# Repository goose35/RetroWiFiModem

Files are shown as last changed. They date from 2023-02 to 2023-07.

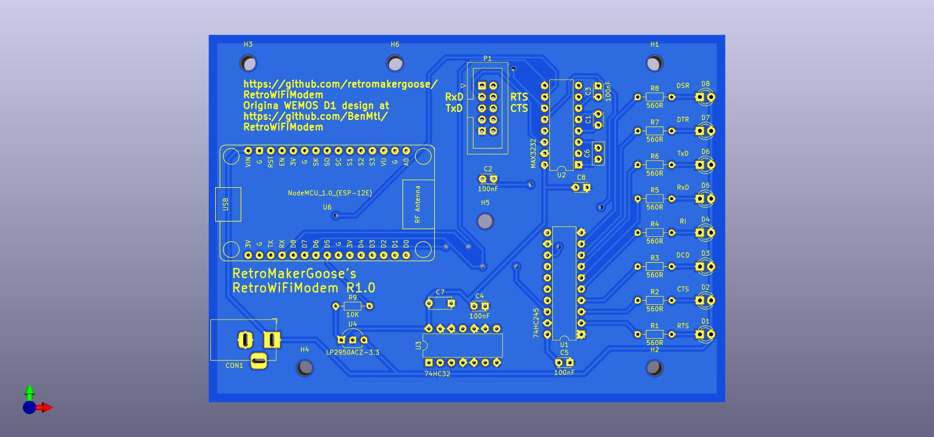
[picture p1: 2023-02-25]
images/MyRetroWiFiModemF.jpg

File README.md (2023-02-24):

# Retro WiFi modem

Forked from BenMtl's repository.
Modified to use a NodeMCU board, of which i had several in waiting.
Will be using on a C64, BBC Micro and Amiga A1200 so will require several adapter leads

# Important Note

Please note that there are 2 standards (pin-outs) for the 10 pin motherboard connector
AT/Everex or Intel/DTK
This modem is using the Intel/DTK pinout
Therefore be aware of this when buying/making your connections to the modem serial port

## The Software

In a nod to its popularity, the command set I used largely follows that
used in [Paul Rickards' WiFi232](http://biosrhythm.com/?page_id=1453)
modem. Even if the innards are completely different, it made sense to
make it *work* like what people were already used to. There's a reason
everyone's been copying the Hayes command set for almost 40 years!

### First time setup

The default serial configuration is 1200bps, 8 data bits, no parity, 1
stop bit.

Here's the commands you need to set up the modem to automatically
connect to your WiFi network:

1. `AT$SSID=your WiFi network name` to set the WiFi network that the
modem will connect to when it powers up.
2. `AT$PASS=your WiFi network password` to set the password for the
network.
3. `ATC1` to connect to the network.
4. Optional stuff:
   * `AT$SB=speed` to set the default serial speed.
   * `AT$SU=dps` to set the data bits, parity and stop bits.
   * `ATNETn` to select whether or not to use Telnet protocol.
   * `AT&Kn` to use RTS/CTS flow control or not.
5. `AT&W` to save the settings.

Once you've done that, the modem will automatically connect to your WiFi
network on power up and will be ready to "dial up" a connection with
ATDT.

### Command Reference

Multiple AT commands can be typed in on a single line. Spaces between
commands are allowed, but not within commands (i.e. AT S0=1 X1 Q0 is
fine; ATS 0=  1 is not). Commands that take a string as an argument
(e.g. AT$SSID=, AT$TTY=) assume that *everything* that follows is a part
of the string, so no commands are allowed after them.

Command | Details
------- | -------
+++     | Online escape code. Once your modem is connected to another device, the only command it recognises is an escape code of a one second pause followed by three typed plus signs and another one second pause, which puts the modem back into local command mode.
A/      | Repeats the last command entered. Do not type AT or press Enter.
AT      | The attention prefix that precedes all command except A/ and +++.
AT?     | Displays a help cheatsheet.
ATA     | Force the modem to answer an incoming connection when the conditions for auto answer have not been satisfied.
ATC?<br>ATC*n* | Query or change the current WiFi connection status. A result of 0 means that the modem is not connected to WiFi, 1 means the modem is connected. The command ATC0 disconnects the modem from a WiFi connection. ATC1 connects the modem to the WiFi.
ATDS*n* | Calls the host specified in speed dial slot *n* (0-9).
ATDT<i>[+=-]host[:port]</i> | Tries to establish a WiFi TCP connection to the specified host name or IP address. If no port number is given, 23 (Telnet) is assumed. You can also use ATDT to dial one of the speed dial slots in one of two ways:<br><br><ul><li>The alias in each speed dial slot is checked to see if it matches the specified hostname.</li><li>A host specified as 7 identical digits dials the slot indicated by the digit. (i.e. 2222222 would speed dial the host in slot 2).</li></ul>Preceding the host name or IP address with a +, = or - character overrides the ATNET setting for the period of the connection.<br><br><ul><li>**+** forces NET2 (fake Telnet)</li><li>**=** forces NET1 (real Telnet)</li><li>**-** forces NET0 (no Telnet)</li></ul>Once the dial attempt has begun, pressing any key before the connection is established will abort the attempt.
ATE?<br>ATE*n* | Command mode echo. Enables or disables the display of your typed commands.<br><br><ul><li>E0 Command mode echo OFF. Your typing will not appear on the screen.</li><li>E1 Command mode echo ON. Your typing will appear on the screen.</li></ul>
ATGET*http&#58;//host[/page]* | Displays the contents of a website page. **https** connections are not supported. Once the contents have been displayed, the connection will automatically terminate.
ATH | Hangs up (ends) the current connection.
ATI | Displays the current network status, including sketch build date, WiFi and call connection state, SSID name, IP address, and bytes transferred.
ATNET?<br>ATNET*n* | Query or change whether telnet protocol is enabled. A result of 0 means that telnet protocol is disabled; 1 is *Real* telnet protocol and 2 is *Fake* telnet protocol. If you are connecting to a telnet server, it may expect the modem to respond to various telnet commands, such as terminal name (set with `AT$TTY`), terminal window size (set with `AT$TTS`) or terminal speed. Telnet protocol should be enabled for these sites, or you will at best see occasional garbage characters on your screen, or at worst the connection may fail.<br><br>The difference between *real* and *fake* telnet protocol is this: with *real* telnet protocol, a carriage return (CR) character being sent from the modem to the telnet server always has a NUL character added after it. The implementation of the telnet protocol used by some BBSes doesn't properly strip out the NUL character. When connecting to such BBSes (Particles! is one), use *fake* telnet.<br><br>When using *real* telnet protocol, when the telnet server sends a CR character followed by a NUL character, only the CR character will be sent to the serial port; the NUL character will be silently stripped out. With *fake* telnet protocol, the NUL will be passed through.
ATO | Return online. Use with the escape code (+++) to toggle between command and online modes.
ATQ?<br>ATQ*n* | Enable or disable the display of result codes. The default is Q0.<br><br><ul><li>Q0 Display result codes.</li><li>Q1 Suppress result codes (quiet).</li></ul>
ATRD<br>ATRT | Displays the current UTC date and time from NIST in the format *YY-MM-DD HH:MM:SS*. A WiFi connection is required and you cannot be connected to another site.
ATS0?<br>ATS0=*n* | Display or set the number of "rings" before answering an incoming connection. Setting `S0=0` means "don't answer".
ATV?<br>ATV*n* | Display result codes in words or numbers. The default is V1.<br><br><ul><li>V0 Display result codes in numeric form.</li><li>V1 Display result codes in text form.</li></ul>
ATX?<br>ATX*n* | Control the amount of information displayed in the result codes. The default is X1 (extended codes).<br><br><ul><li>X0 Display basic codes (CONNECT, NO CARRIER)</li><li>X1 Display extended codes (CONNECT speed, NO CARRIER (connect time))</li></ul>
ATZ | Resets the modem.
AT&F | Reset the NVRAM contents and current settings to the sketch defaults. All settings, including SSID name, password and speed dial slots are affected.
AT&K?<br>AT&K*n* | Data flow control. Prevents the modem's buffers for received and transmitted from overflowing.<br><br><ul><li>&K0 Disable data flow control.</li><li>&K1 Use hardware flow control. Requires that your computer and software support Clear to Send (CTS) and Request to Send (RTS) at the RS-232 interface.</li></ul>
AT&R?<br>AT&R=*server pwd* | Query or change the password for incoming connections. If set, the user has 3 chances in 60 seconds to enter the correct password or the modem will end the connection.
AT&V*n* | Display current or stored settings.<br><br><ul><li>&V0 Display current settings.</li><li>&V1 Display stored settings.</li></ul>
AT&W | Save current settings to NVRAM.
AT&Zn?<br>AT&Z*n*=*host[:port],alias* | Store up to 10 numbers in NVRAM, where *n* is the position 0-9 in NVRAM, and *host[:port]* is the host string, and *alias* is the speed dial alias name. The host string may be up to 50 characters long, and the alias string may be up to 16 characters long.<br><br>Example: `AT&Z2=particlesbbs.dyndns.org:6400,particles`<br><br>This number can then be dialed in any of the following ways:<br><br><ul><li>`ATDS2`</li><li>`ATDTparticles`</li><li>`ATDT2222222`</li></ul>
AT$AE?<br>AT$AE=*startup AT cmd* | Query or change the command line to be executed when the modem starts up.
AT$BM?<br>AT$BM=*server busy msg* | Query or change a message to be returned to an incoming connection if the modem is busy (i.e. already has a connection established).
AT$MDNS<br>AT$MDNS=*mDNS name* | Query or change the mDNS network name (defaults to "espmodem"). When a non zero TCP port is defined, you can telnet to that port with **telnet mdnsname.local port**.
AT$PASS?<br>AT$PASS=*WiFi pwd* | Query or change the current WiFi password. The password is case sensitive. Clear the password by issuing the set command with no password. The maximum length of the password is 64 characters.
AT$SB?<br>AT$SB=*n* | Query or change the current baud rate. Valid values for "n" are 110, 300, 450, 600, 710, 1200, 2400, 4800, 9600, 19200, 38400, 57600, 76800 and 115200. Any other value will return an ERROR message. The default baud rate is 1200. The Retro WiFi modem does not automatically detect baud rate like a dial-up modem. The baud rate setting must match that of your terminal to operate properly. It will display garbage in your terminal otherwise.
AT$SP?<br>AT$SP=*n* | TCP server port to listen on. A value of 0 means that the TCP server is disabled, and no incoming connections are allowed.
AT$SSID?<br>AT$SSID=*ssid name* | Query or change the current SSID to the specified name. The given SSID name is case sensitive. Clear the SSID by issuing the set command with no SSID. The maximum length of the SSID name is 32 characters.
AT$SU?<br>AT$SU=*dps* | Query or change the current number of data bits ('d'), parity ('p') and stop bits ('s") of the serial UART. Valid values for 'd' are 5, 6, 7 or 8 bits. Valid values for 'p' are (N)one, (O)dd or (E)ven parity. Valid values for 's' are 1 or 2 bits. The default settings are 8N1. The UART setting must match your terminal to work properly.
AT$TTL?<br>AT$TTL=*telnet location* | Query or change the Telnet location value to be returned when the Telnet server issues a SEND-LOCATION request. The default value is "Computer Room".
AT$TTS?<br>AT$TTS=*WxH* | Query or change the window size (columns x rows) to be returned when the Telnet server issues a NAWS (Negotiate About Window Size) request. The default value is 80x24. For terminals that are smaller than 80x24, setting these values appropriately will enable paging on the help (AT?) and network status (ATI) commands.
AT$TTY?<br>AT$TTY=*terminal type* | Query or change the terminal type to be returned when the Telnet server issues a TERMINAL-TYPE request. The default value is "ansi".
AT$W?<br>AT$W=*n* | Startup wait.<br><br><ul><li>$W=0 Startup with no wait.</li><li>$W=1 Wait for the return key to be pressed at startup.</li></ul>

### Updating the Software

While I liked the idea of being able to update the software OTA, it
seemed to make more sense in my situation to be able to *push* a new
version as I built it rather than have the modem *pull* it. So that's
what I did. It uses the default OTA upload capability built into the
Arduino IDE.

**Jan 24/22:** It's been reported that the ESP8266 core is slightly
snafu'd at the moment, and that it's breaking things in the modem
software. As a workaround, I've added the bin file that gets uploaded
to the modem in the repository. I haven't updated my ESP8266 core in
ages; "if it isn't broken, don't break it", and everything still works
for me. The bin file can be uploaded with the *espota.py* tool in the
ESP8266 tool directory tree.

(If TPTB have deleted/renamed/moved that tool in the current core,
you'll have to figure out how to do a manual OTA update.)

### RTS/CTS handshaking and a dead spin loop issue

Something I noticed with ESP8266 software that puzzled me was the
number of places I saw a series of Serial print statements being broken
up with calls to yield(), like so:

```
   Serial.print("Hello world!\n");
   yield();
   Serial.print("How are you today?\n");
   yield();
```
It didn't take long to figure out what was going on; The print() call
was blocking, and at lower baud rates, even printing a few relatively
short strings was enough to cause the watchdog to bark and cause a
reset. So the repetitive yield() calls were an attempt to feed the
watchdog often enough to keep it from barking.

What does this have to do with RTS/CTS handshaking? Simply put,
lowering RTS for more than a few seconds was causing the watchdog to
bark as well. So I started digging.

In cores/esp8266/uart.cpp I found the following function:

```
static void
uart_do_write_char(const int uart_nr, char c)
{
    while(uart_tx_fifo_full(uart_nr));

    USF(uart_nr) = c;
}
```

This is the low level function that everything calls to send a character
out the serial port. The cause of the watchdog barking is in the dead
spin while loop. It waits until there's room in the transmit FIFO to add
another character. So if RTS/CTS handshaking is enabled, and RTS is low
for longer than the watchdog likes: woof.

What I did to quiet the watchdog down both when sending long strings at
low baud rates and during long waits for RTS to come active again was to
add a yield() call to the dead spin while loop, like so:

```
static void
uart_do_write_char(const int uart_nr, char c)
{
    while(uart_tx_fifo_full(uart_nr))
      yield();

    USF(uart_nr) = c;
}
```

This way, no matter how long the code has to wait for space in the
transmit FIFO, the watchdog is kept well fed and quiet.

## Status

Is a personal project like this ever *really* finished? I've had two
units assembled and in use since the spring of 2020, and while there's
been some software changes since then, I really don't expect any more.
There are no outstanding bugs that I'm aware of, and no new features on
my wish list. For the time being at least, I think it's complete.

### Linux, Telnet, Zmodem and downloading binary files

Have you used the modem to 'dial' into a Linux box? And have you done a
`sz binary_file` on the Linux box? And at a completely reproducible
point in the file, has the connection dropped? But other binary files
work just fine? Then read on.

This drove me slightly batty for months. I finally narrowed it down to
trying to send blocks of binary data with a large number of FF bytes. I
eventually created a test file consisting of 2K of FF and used that to
test with. I could download it through the modem with Xmodem just fine.
Ymodem also worked if I kept the block size down to 128 bytes - but the
connection would drop instantly if I tried sending 1K blocks. Same thing
with Zmodem.

In fact, if I just tried `cat binary_file`, the connection would
drop. Which eventually got me thinking. Sitting at the console on my
main Linux box, I telnet'd to the same box and logged in. No WiFi modem
involved anywhere, just a telnet session on the console to the same box.
I then did a `cat binary_file`. The telnet connection dropped, and I
was back in my original session.

It's the Linux telnet daemon. Not the modem at all.

To prove it to myself, I hooked up WiFi modems to two systems on their
serial ports and had one dial into the other. I could send the all FF
binary file back and forth with Zmodem and Ymodem, no trouble at all.

But you really, really need to download that binary file through the
modem from a telnet connection to a Linux box? You're not going to be
able to use Zmodem. Ymodem will work (the sy command defaults to 128
byte blocks), as will Xmodem. But not Zmodem.

Oddly enough, the telnet daemon has no trouble *receiving* the all FF
binary file. Only sending it. Your guess as to why is probably better
than mine.

## References

* [WiFi232 - An Internet Hayes Modem for your Retro Computer](http://biosrhythm.com/?page_id=1453)<br>
* [WiFi232's Evil Clone](https://forum.vcfed.org/index.php?threads/wifi232s-evil-clone.1070412/)<br>
* [Jussi Salin's Virtual modem for ESP8266](https://github.com/jsalin/esp8266_modem)<br>
* [Stardot's ESP8266 based virtual modem](https://github.com/stardot/esp8266_modem)<br>
* [Roland Juno's ESP8266 based virtual modem](https://github.com/RolandJuno/esp8266_modem)

## Acknowledgements

* A whole lot of people owe a big vote of thanks to Jussi Salin for
releasing their virtual modem code for the ESP8266 and starting the
ball rolling.
* Paul Rickards for an amazing bit of hardware to draw inspiration from.
* All the Stardot contributors for their work.
* And, of course, Dennis C. Hayes for creating something so simple and
elegant that has stood the test of time.

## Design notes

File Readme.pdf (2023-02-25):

Doc Rev. 1.0.0

Page 1 of 9

### 24 February 2023

Stephen Orton

# Retro WiFi modem

Introduction
This is my version of the RetroWiFiModem. All I have done is modify the PCB layout to use a Node MCU development board instead of the original Wemos D1 Mini

The code was also modified to include Node MCU support

Important Note
Please note that there are 2 standards (pin-outs) for the 10 pin motherboard connector AT/Everex or Intel/DTK
This modem is using the Intel/DTK pinout
Therefore be aware of this when buying/making your connections to the modem serial port

Post Build Setup
The default serial configuration is 1200bps, 8 data bits, no parity, 1
stop bit.
1. `AT$SSID=your WiFi network name` to set the WiFi network that the modem will connect to when it powers up.
2. `AT$PASS=your WiFi network password` to set the password for the network.
3. `ATC1` to connect to the network.

### 4. Optional stuff:

* `AT$SB=speed` to set the default serial speed.
* `AT$SU=dps` to set the data bits, parity and stop bits.
* `ATNETn` to select whether or not to use Telnet protocol.
* `AT&Kn` to use RTS/CTS flow control or not.
5. `AT&W` to save the settings.

Once you've done that, the modem will automatically connect to your WiFi network on power up and will be ready to "dial up" a connection with ATDT. Command Reference
Multiple AT commands can be typed in on a single line. Spaces between commands are allowed, but not within commands (i.e. AT S0=1 X1 Q0 is fine; ATS 0= 1 is not). Commands that take a string as an argument
(e.g. AT$SSID=, AT$TTY=) assume that *everything* that follows is a part of the string, so no commands are allowed after them.

Page 2 of 9

Command | Details
+++ | Online escape code. Once your modem is connected to another device, the only command it recognises is an escape code of a one second pause followed by three typed plus signs and another one second pause, which puts the modem back into local command mode.
A/ | Repeats the last command entered. Do not type AT or press Enter.
AT | The attention prefix that precedes all command except A/ and +++.
AT? | Displays a help cheatsheet.
ATA | Force the modem to answer an incoming connection when the conditions for auto answer have not been satisfied.
ATC? ATC*n* | Query or change the current WiFi connection status. A result of 0 means that the modem is not connected to WiFi, 1 means the modem is connected. The command ATC0 disconnects the modem from a WiFi connection. ATC1 connects the modem to the WiFi.
ATDS*n* | Calls the host specified in speed dial slot *n* (0-9).
ATDT<i>[+=-
]host[:port]

Tries to establish a WiFi TCP connection to the specified host name or IP address. If no port number is given, 23 (Telnet) is assumed. You can also use ATDT to dial one of the speed dial slots in one of two ways:<br><br><ul><li>The alias in each speed dial slot is checked to see if it matches the specified hostname.</li><li>A host specified as 7 identical digits dials the slot indicated by the digit. (i.e. 2222222 would speed dial the host in slot 2).</li></ul>Preceding the host name or IP address with a +, = or - character overrides the ATNET setting for the period of the
connection.<br><br><ul><li>**+** forces NET2 (fake Telnet)</li><li>**=** forces NET1 (real Telnet)</li><li>**-** forces NET0 (no Telnet)</li></ul>Once the dial attempt has begun, pressing any key before the connection is established will abort the attempt.
ATE?
ATE*n*

Command mode echo. Enables or disables the display of your typed commands.<br><br><ul><li>E0 Command mode echo OFF. Your typing will not appear on the screen.</li><li>E1 Command mode echo ON. Your typing will appear on the screen.</li></ul>

Page 3 of 9

ATGET*http&#5 8;//host[/page] * | Displays the contents of a website page. **https** connections are not supported. Once the contents have been displayed, the connection will automatically terminate.
ATH | Hangs up (ends) the current connection.
ATI | Displays the current network status, including sketch build date, WiFi and call connection state, SSID name, IP address, and bytes transferred.

ATNET?
ATNET*n*

Query or change whether telnet protocol is enabled. A result of 0 means that telnet protocol is disabled; 1 is *Real* telnet protocol and 2 is *Fake* telnet protocol. If you are connecting to a telnet server, it may expect the modem to respond to various telnet commands, such as terminal name (set with `AT$TTY`), terminal window size (set with `AT$TTS`) or terminal speed. Telnet protocol should be enabled for these sites, or you will at best see occasional garbage characters on your screen, or at worst the connection may fail.<br><br>The difference between *real* and *fake* telnet protocol is this: with *real* telnet protocol, a carriage return (CR) character being sent from the modem to the telnet server always has a NUL character added after it. The implementation of the telnet protocol used by some BBSes doesn't properly strip out the NUL character. When connecting to such BBSes (Particles! is one), use *fake* telnet.<br><br>When using *real* telnet protocol, when the telnet server sends a CR character followed by a NUL character, only the CR character will be sent to the serial port; the NUL character will be silently stripped out. With *fake* telnet protocol, the NUL will be passed through.
ATO | Return online. Use with the escape code (+++) to toggle between command and online modes.
ATQ? ATQ*n* | Enable or disable the display of result codes. The default is Q0. Q0 Display result codes Q1 Suppress result codes (quiet).
ATRD ATRT | Displays the current UTC date and time from NIST in the format *YY-MM-DD HH:MM:SS*. A WiFi connection is required and you cannot be connected to another site.
ATS0? ATS0=*n* | Display or set the number of "rings" before answering an incoming connection. Setting `S0=0` means "don't answer".
ATV? | Display result codes in words or numbers. The default is V1.

Page 4 of 9

ATV*n* | V0 Display result codes in numeric form. V1 Display result codes in text form.</li></ul>
ATX? ATX*n* | Control the amount of information displayed in the result codes. The default is X1 (extended codes). Display basic codes (CONNECT, NO CARRIER). X1 Display extended codes (CONNECT speed, NO CARRIER (connect time))</li></ul>
ATZ | Resets the modem.
AT&F | Reset the NVRAM contents and current settings to the sketch defaults. All settings, including SSID name, password and speed dial slots are affected.
AT&K? AT&K*n* | Data flow control. Prevents the modem's buffers for received and transmitted from overflowing. &K0 Disable data flow control. &K1 Use hardware flow control. Requires that your computer and software support Clear to Send (CTS) and Request to Send (RTS) at the RS-232 interface.
AT&R? AT&R=*server pwd* | Query or change the password for incoming connections. If set, the user has 3 chances in 60 seconds to enter the correct password or the modem will end the connection.
AT&V*n* | Display current or stored settings. &V0 Display current settings. &V1 Display stored settings.
AT&W | Save current settings to NVRAM.
AT&Zn? AT&Z*n*=*host [:port],alias* | Store up to 10 numbers in NVRAM, where *n* is the position 0-9 in NVRAM, and *host[:port]* is the host string, and *alias* is the speed dial alias name. The host string may be up to 50 characters long, and the alias string may be up to 16 characters long. Example: `AT&Z2=particlesbbs.dyndns.org:6400,particles` This number can then be dialed in any of the following ways: `ATDS2` `ATDTparticles` `ATDT2222222`
AT$AE? AT$AE=*startup AT cmd* | Query or change the command line to be executed when the modem starts up.
AT$BM? AT$BM=*server busy msg* | Query or change a message to be returned to an incoming connection if the modem is busy (i.e. already has a connection established).
AT$MDNS AT$MDNS=*mD NS name* | Query or change the mDNS network name (defaults to "espmodem"). When a non zero TCP port is defined, you can telnet to that port with **telnet mdnsname.local port**.

Page 5 of 9

AT$PASS? AT$PASS=*WiFi pwd* | Query or change the current WiFi password. The password is case sensitive. Clear the password by issuing the set command with no password. The maximum length of the password is 64 characters.
AT$SB? AT$SB=*n* | Query or change the current baud rate. Valid values for "n" are 110, 300, 450, 600, 710, 1200, 2400, 4800, 9600, 19200, 38400, 57600, 76800 and 115200. Any other value will return an ERROR message. The default baud rate is 1200. The Retro WiFi modem does not automatically detect baud rate like a dial-up modem. The baud rate setting must match that of your terminal to operate properly. It will display garbage in your terminal otherwise.
AT$SP? AT$SP=*n* | TCP server port to listen on. A value of 0 means that the TCP server is disabled, and no incoming connections are allowed.
AT$SSID? AT$SSID=*ssid name* | Query or change the current SSID to the specified name. The given SSID name is case sensitive. Clear the SSID by issuing the set command with no SSID. The maximum length of the SSID name is 32 characters.
AT$SU? AT$SU=*dps* | Query or change the current number of data bits ('d'), parity ('p') and stop bits ('s") of the serial UART. Valid values for 'd' are 5, 6, 7 or 8 bits. Valid values for 'p' are (N)one, (O)dd or (E)ven parity. Valid values for 's' are 1 or 2 bits. The default settings are 8N1. The UART setting must match your terminal to work properly.
AT$TTL? AT$TTL=*telnet location* | Query or change the Telnet location value to be returned when the Telnet server issues a SEND-LOCATION request. The default value is "Computer Room".
AT$TTS? AT$TTS=*WxH* | Query or change the window size (columns x rows) to be returned when the Telnet server issues a NAWS (Negotiate About Window Size) request. The default value is 80x24. For terminals that are smaller than 80x24, setting these values appropriately will enable paging on the help (AT?) and network status (ATI) commands.
AT$TTY? AT$TTY=*termi nal type* | Query or change the terminal type to be returned when the Telnet server issues a TERMINAL-TYPE request. The default value is "ansi".
AT$W? AT$W=*n* | Startup wait $W=0 Startup with no wait. $W=1 Wait for the return key to be pressed at startup.

Page 6 of 9

Updating the Software
The software may be loaded in the normal way or you may use the default OTA upload capability built into the Arduino IDE to upload OTA

References
* WiFi232 - An Internet Hayes Modem for your Retro computer http://biosrhythm.com/?page_id=1453
- WiFi232's Evil Clone
(https://forum.vcfed.org/index.php?threads/wifi232s-evil-clone.1070412/)
- Jussi Salin's Virtual modem for ESP8266 (https://github.com/jsalin/esp8266_modem)
- Stardot's ESP8266 based virtual modem (https://github.com/stardot/esp8266_modem)
- Roland Juno's ESP8266 based virtual modem (https://github.com/RolandJuno/esp8266_modem)

Acknowledgements
- A whole lot of people owe a big vote of thanks to Jussi Salin for releasing their virtual modem code for the ESP8266 and starting the ball rolling.
- Paul Rickards for an amazing bit of hardware to draw inspiration from.
- All the Stardot contributors for their work.
- And, of course, Dennis C. Hayes for creating something so simple and elegant that has stood the test of time.

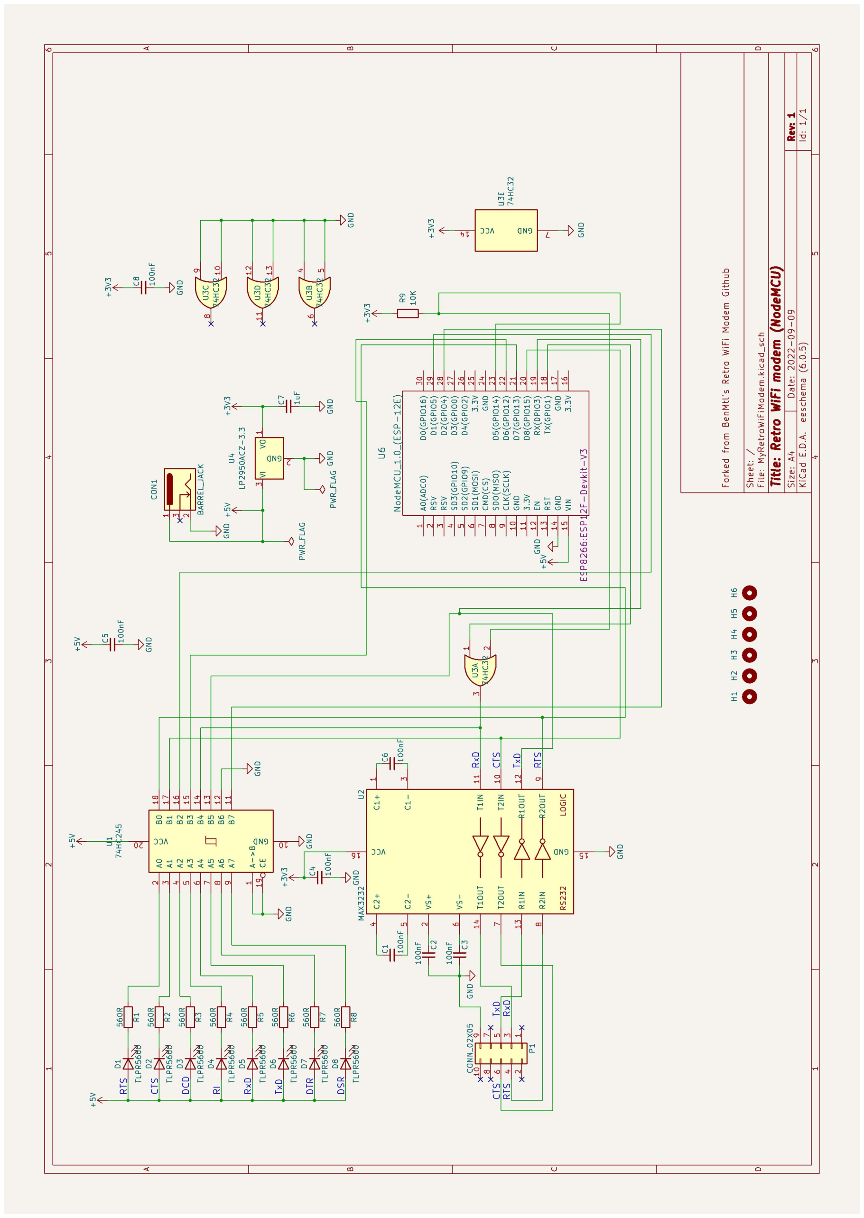
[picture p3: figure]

Page 7 of 9

Schematic

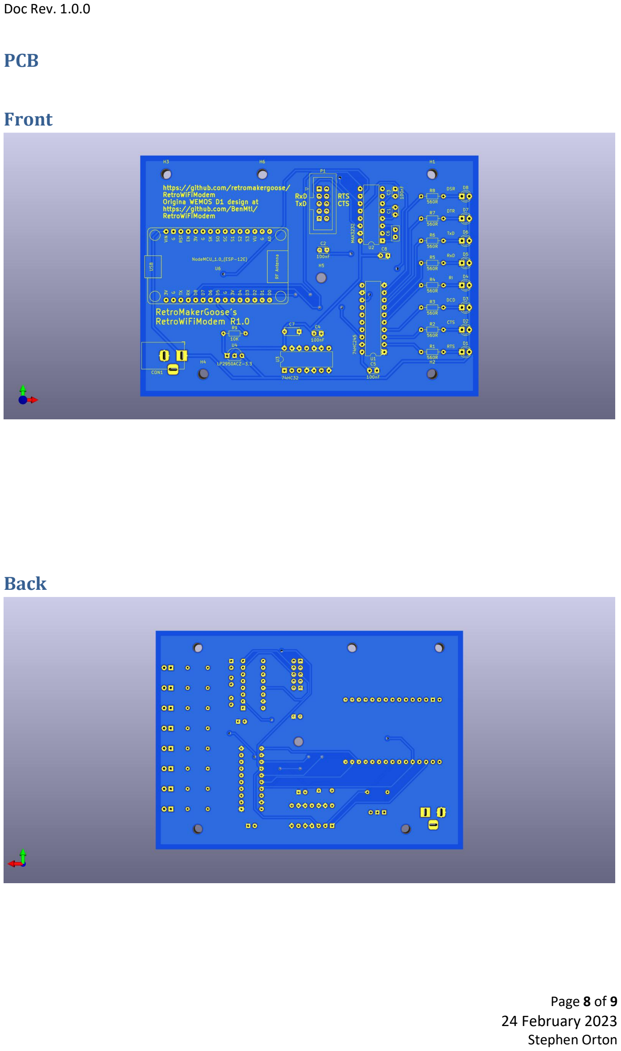
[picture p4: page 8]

Page 8 of 9

PCB

Front

Back

Page 9 of 9

BOM

C7, | 1 | 1uF | Unpolarized capacitor, small symbol
CON1, | 1 | BARREL_JACK | DC Barrel Jack with an internal switch
D1, D2, D3, D4, D5, D6, D7, D8, | 8 | TLPR5600 | Light emitting diode
H1, H2, H3, H4, H5, H6, | 6 | MountingHole | Mounting Hole without connection
P1, | 1 | CONN_02X05 | Generic connector, double row, 02x05, odd/even pin numbering scheme (row 1 odd numbers, row 2 even numbers), script generated (kicad-library-utils/schlib/autogen/connector/)
R1, R2, R3, R4, R5, R6, R7, R8, | 8 | 560R | Resistor
R9, | 1 | 10K | Resistor
U1, | 1 | 74HC245 | Octal BUS Transceivers, 3-State outputs
U2, | 1 | MAX3232 | Dual RS232 driver/receiver, 5V supply, 120kb/s, 0C-70C
U3, | 1 | 74HC32 | Quad 2-input OR
U4, | 1 | LP2950ACZ-3.3 | Positive 100mA 30V Linear Micropower Voltage Regulator, Fixed Output 3.3V, TO-92
U6, | 1 | NodeMCU_1.0_(ESP-12E)

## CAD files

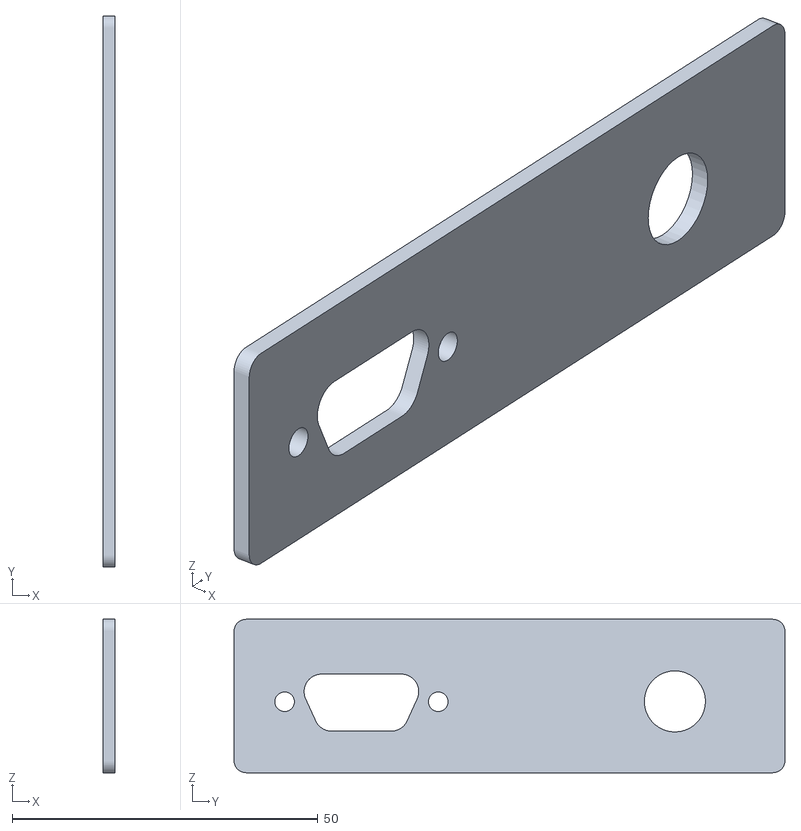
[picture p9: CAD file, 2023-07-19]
case/back1.stl
2.00 x 90.1 x 25.1

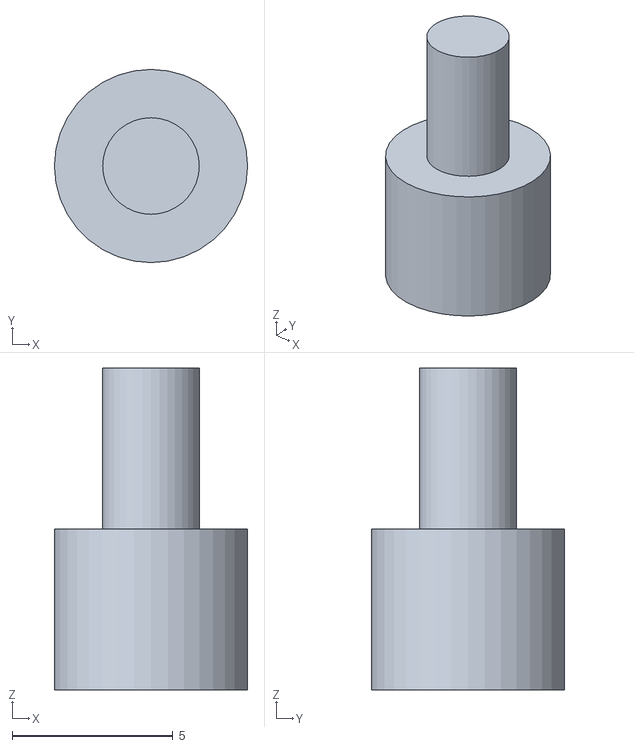
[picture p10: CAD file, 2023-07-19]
case/standoff.stl
6.00 x 6.00 x 10.0

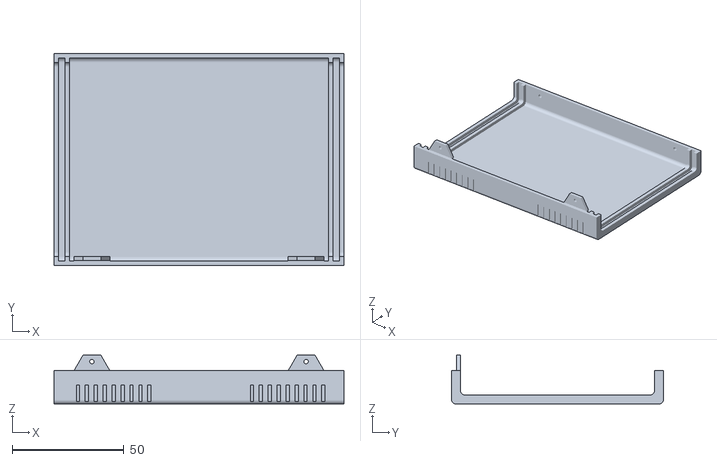
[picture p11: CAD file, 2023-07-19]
case/bottom.stl
130.0 x 95.0 x 21.9

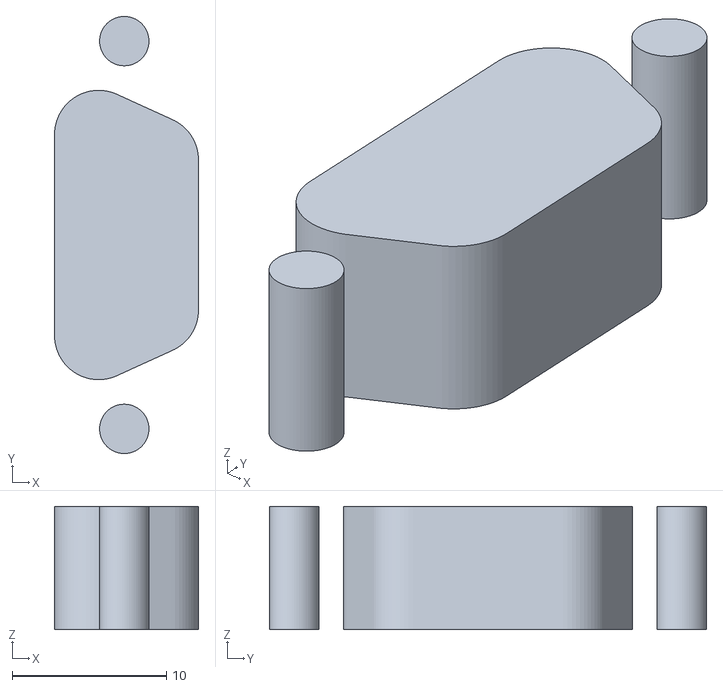
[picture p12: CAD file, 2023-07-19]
case/db9.stl
9.33 x 28.3 x 8.00

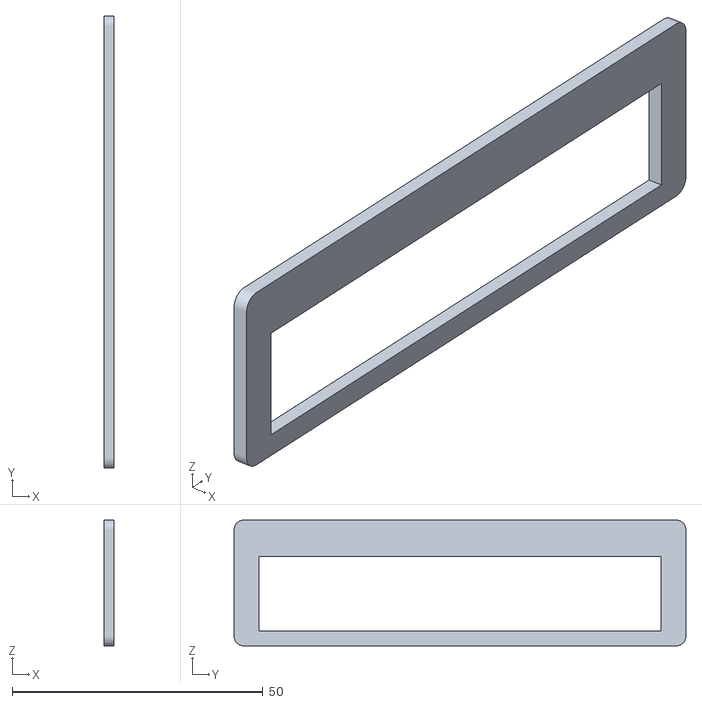
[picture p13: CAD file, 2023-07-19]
case/front1.stl
2.00 x 90.1 x 25.1

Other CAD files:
case/top.stl

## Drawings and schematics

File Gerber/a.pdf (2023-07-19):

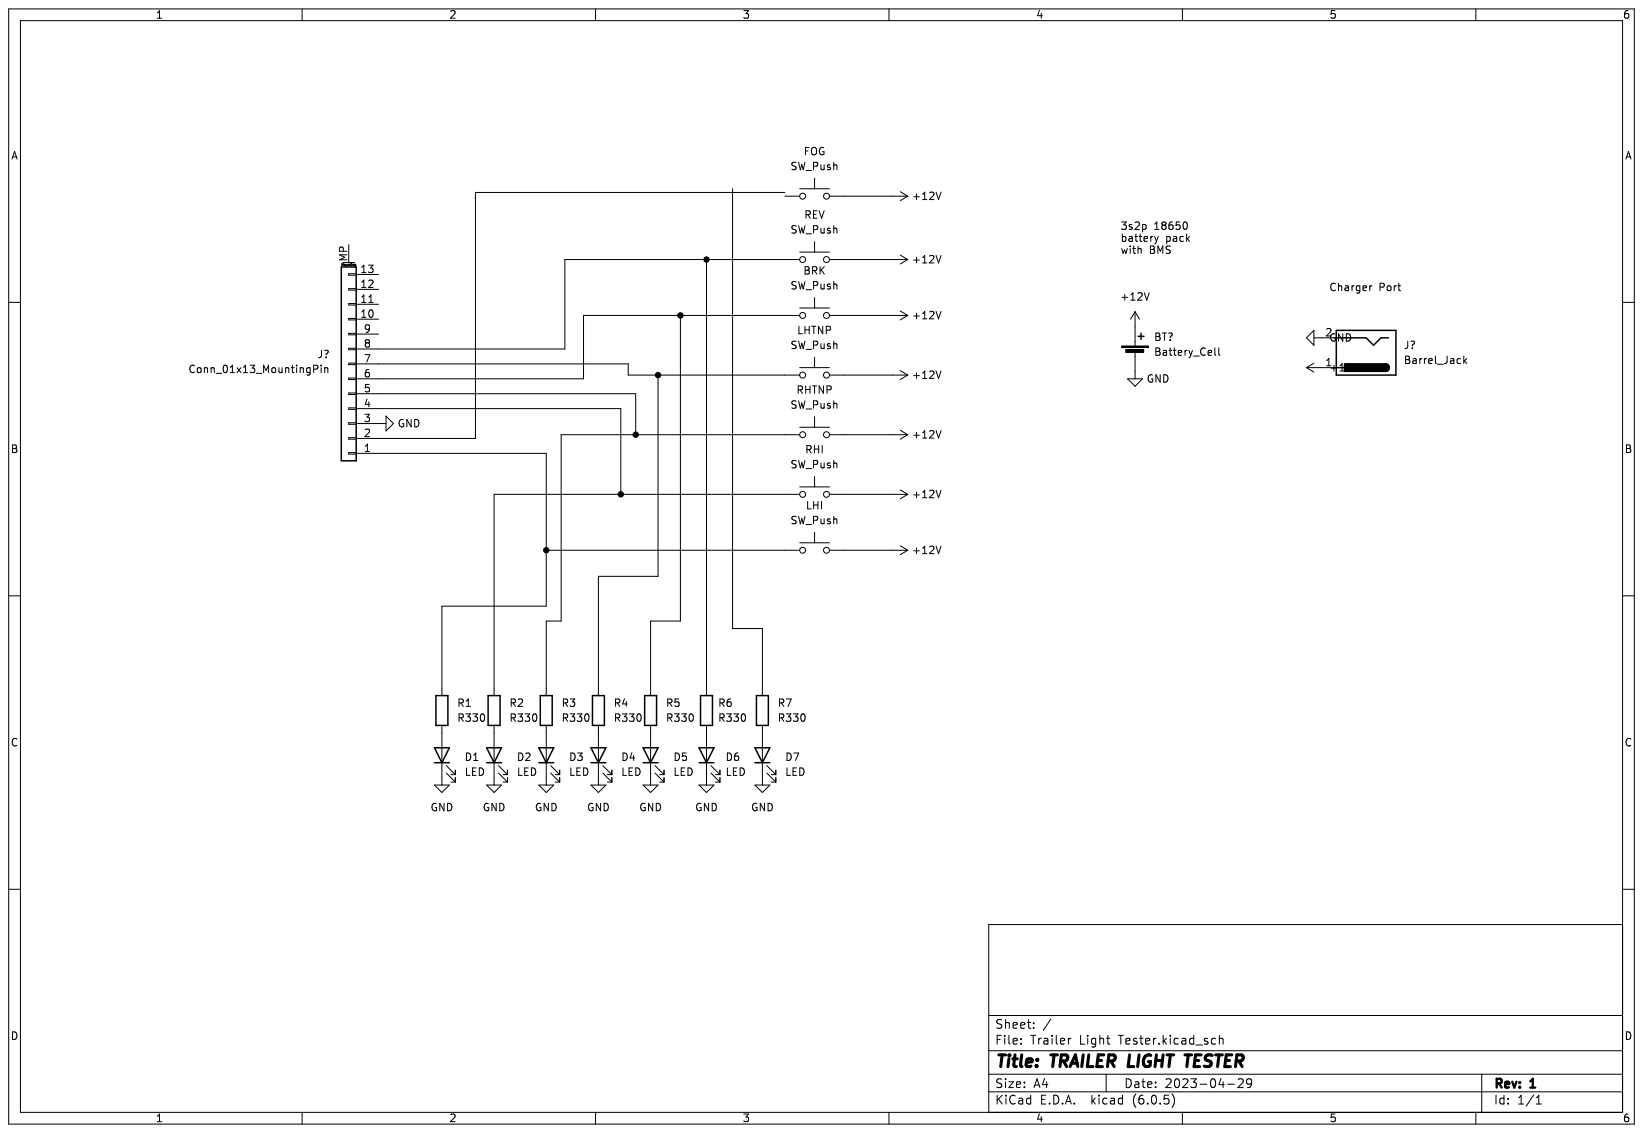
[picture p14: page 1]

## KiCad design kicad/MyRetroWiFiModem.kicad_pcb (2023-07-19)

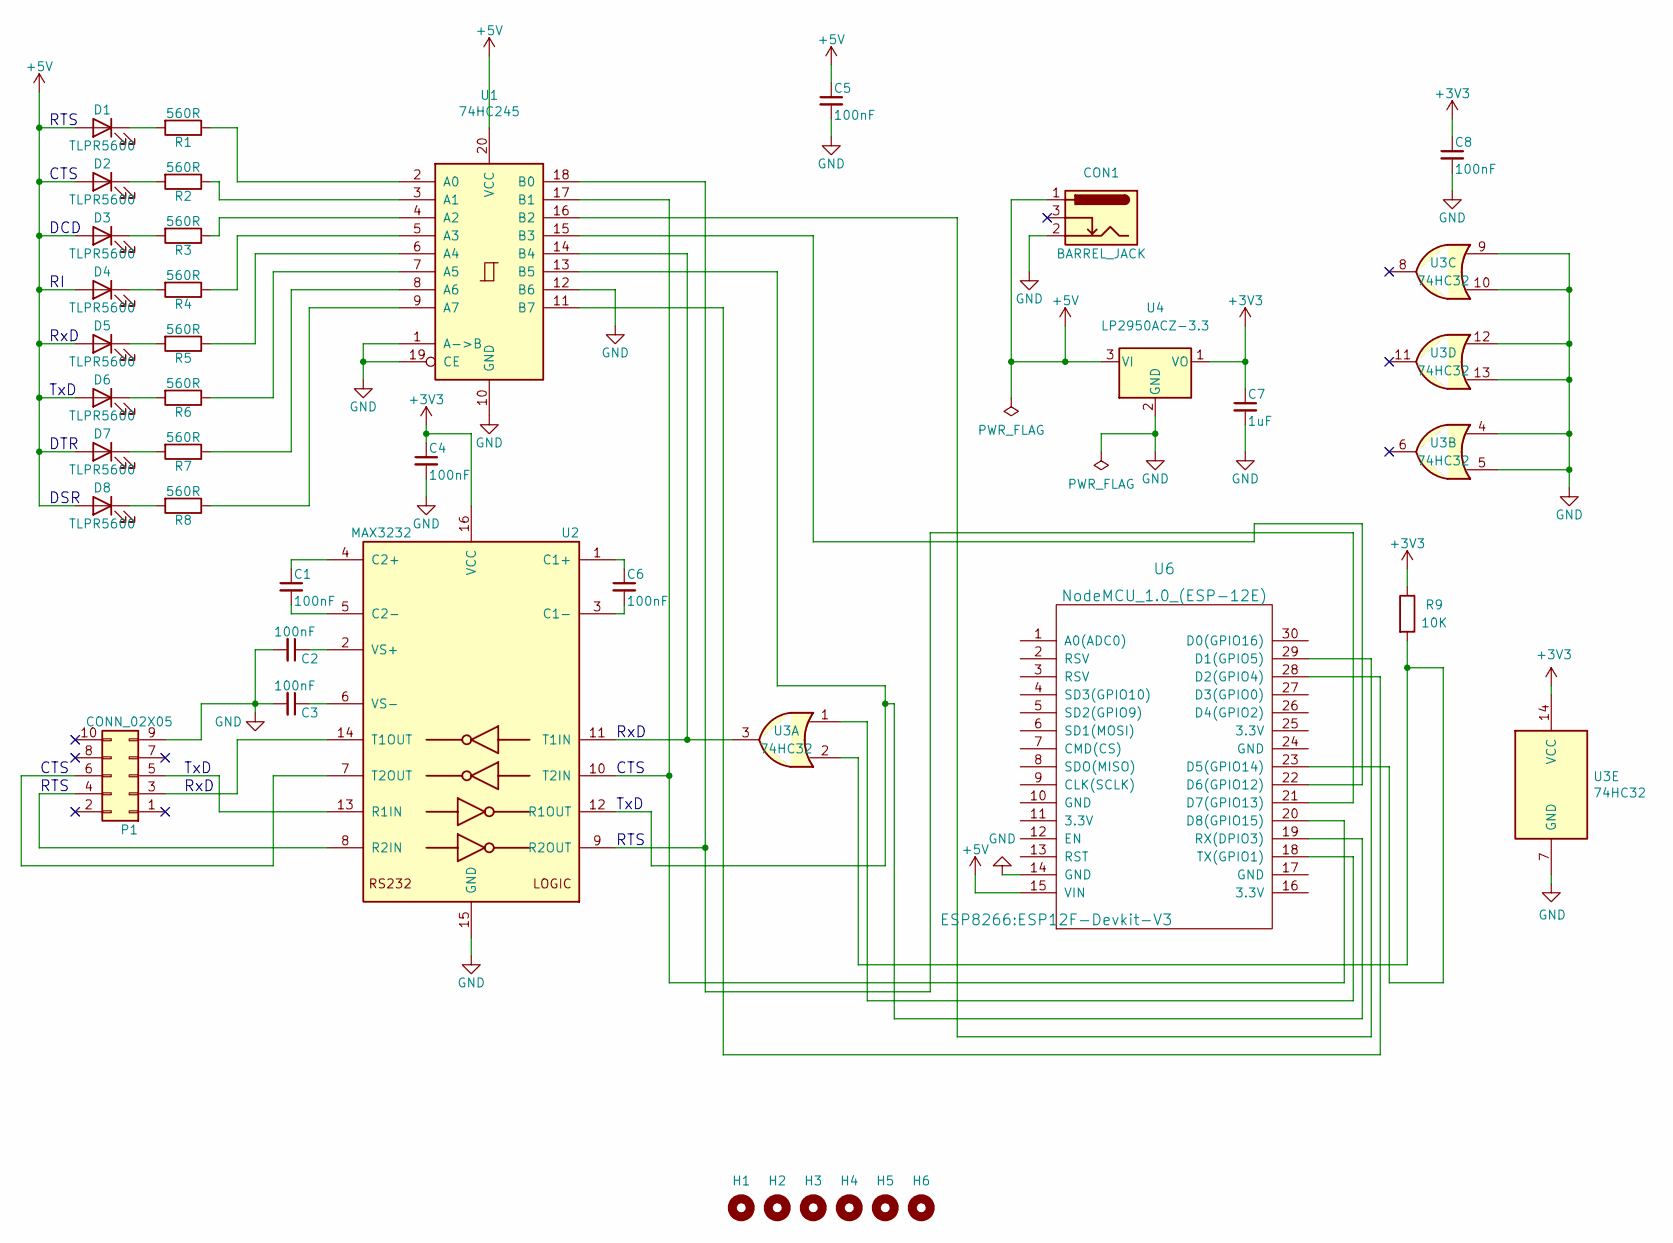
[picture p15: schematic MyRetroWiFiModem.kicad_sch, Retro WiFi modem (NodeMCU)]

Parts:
C1, C2, C3, C4, C5, C8: 100nF; C_Disc_D3.0mm_W2.0mm_P2.50mm; DigiKey PN 399-9859-1-ND
C6: 100nF; C_Disc_D5.0mm_W2.5mm_P2.50mm; DigiKey PN 399-9843-ND
C7: 1uF; C_Disc_D5.0mm_W2.5mm_P5.00mm; DigiKey PN 399-3529-ND
CON1: BARREL_JACK; BarrelJack_Horizontal; DigiKey PN 839-54-00166-ND
D1, D2, D3, D4, D5, D6, D7, D8: TLPR5600; LED_D3.0mm; DigiKey PN TLPR5600-ND
H1, H2, H3, H4, H5, H6: MountingHole; MountingHole_3.2mm_M3
P1: CONN_02X05; IDC-Header_2x05_P2.54mm_Vertical; DigiKey PN ED1543-ND
R1, R2, R3, R4, R5, R6, R7, R8: 560R; R_Axial_DIN0204_L3.6mm_D1.6mm_P7.62mm_Horizontal; DigiKey PN CF18JT560RCT-ND
R9: 10K; R_Axial_DIN0204_L3.6mm_D1.6mm_P7.62mm_Horizontal; DigiKey PN CF18JT10K0CT-ND
U1: 74HC245; DIP-20_W7.62mm; DigiKey PN 296-1612-5-ND
U2: MAX3232; DIP-16_W7.62mm; DigiKey PN ICL3232CPZ-ND
U3: 74HC32; DIP-14_W7.62mm; DigiKey PN 296-1589-5-ND
U4: LP2950ACZ-3.3; TO-92L_Inline_Wide; DigiKey PN LP2950ACZ-3.3GOS-ND
U6: NodeMCU_1.0_(ESP-12E); ESP12F-Devkit-V3

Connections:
+3V3: C4.1, C7.1, C8.1, R9.1, U2.16 (VCC), U3.14 (VCC), U4.1 (VO)
+5V: C5.1, CON1.1, D1.2 (A), D2.2 (A), D3.2 (A), D4.2 (A), D5.2 (A), D6.2 (A), D7.2 (A), D8.2 (A), U1.20 (VCC), U4.3 (VI), U6.15 (VIN)
GND: C2.2, C3.2, C4.2, C5.2, C7.2, C8.2, CON1.2, P1.9, U1.1 (A->B), U1.10 (GND), U1.12 (B6), U1.19 (CE), U2.15 (GND), U3.4, U3.5, U3.7 (GND), U3.9, U3.10, U3.12, U3.13, U4.2 (GND), U6.14 (GND)
unnamed: C1.1, U2.4 (C2+)
unnamed: C1.2, U2.5 (C2-)
unnamed: C2.1, U2.2 (VS+)
unnamed: C3.1, U2.6 (VS-)
unnamed: C6.1, U2.1 (C1+)
unnamed: C6.2, U2.3 (C1-)
unnamed: D1.1 (K), R1.2
unnamed: D2.1 (K), R2.2
unnamed: D3.1 (K), R3.2
unnamed: D4.1 (K), R4.2
unnamed: D5.1 (K), R5.2
unnamed: D6.1 (K), R6.2
unnamed: D7.1 (K), R7.2
unnamed: D8.1 (K), R8.2
unnamed: P1.3, U2.14 (T1OUT)
unnamed: P1.4, U2.8 (R2IN)
unnamed: P1.5, U2.13 (R1IN)
unnamed: P1.6, U2.7 (T2OUT)
unnamed: R1.1, U1.2 (A0)
unnamed: R2.1, U1.3 (A1)
unnamed: R3.1, U1.4 (A2)
unnamed: R4.1, U1.5 (A3)
unnamed: R5.1, U1.6 (A4)
unnamed: R6.1, U1.7 (A5)
unnamed: R7.1, U1.8 (A6)
unnamed: R8.1, U1.9 (A7)
unnamed: R9.2, U3.2, U6.23 (D5(GPIO14))
unnamed: U1.11 (B7), U6.28 (D2(GPIO4))
unnamed: U1.13 (B5), U2.12 (R1OUT), U6.19 (RX(DPIO3))
unnamed: U1.14 (B4), U2.11 (T1IN), U3.3
unnamed: U1.15 (B3), U6.22 (D6(GPIO12))
unnamed: U1.16 (B2), U6.29 (D1(GPIO5))
unnamed: U1.17 (B1), U2.10 (T2IN), U6.20 (D8(GPIO15))
unnamed: U1.18 (B0), U2.9 (R2OUT), U6.21 (D7(GPIO13))
unnamed: U3.1, U6.18 (TX(GPIO1))

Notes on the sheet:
TxD
CTS
RxD
RTS
DSR
DCD
DTR

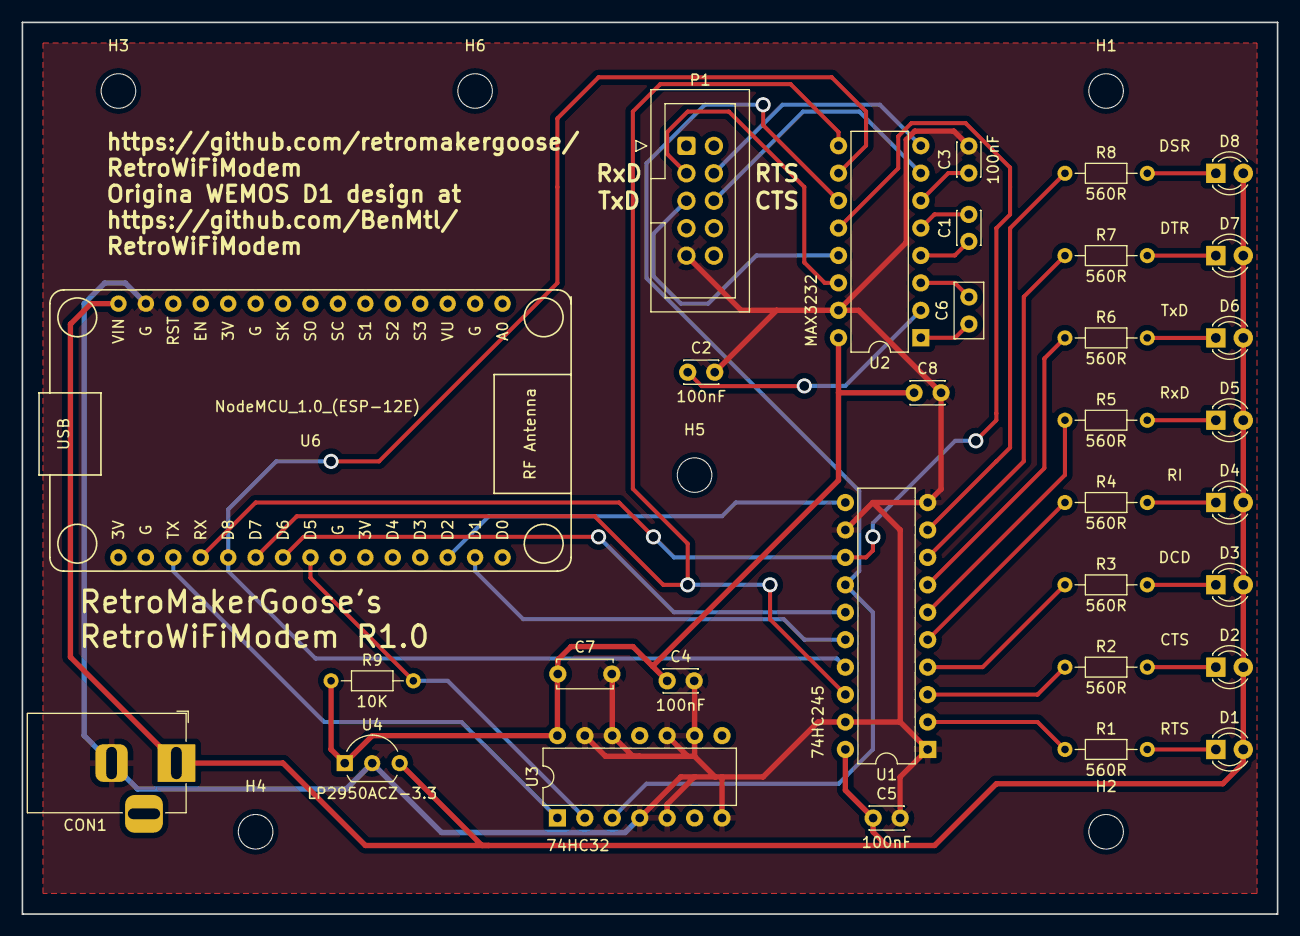
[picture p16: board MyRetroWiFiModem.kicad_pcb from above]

Board: 2 copper layers, 116.2 x 82.5 mm, 38 parts (0 on the bottom side), 38 nets.

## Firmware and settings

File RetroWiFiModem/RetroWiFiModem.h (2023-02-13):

#ifndef _MODEM_H
   #define _MODEM_H

   #define DEBUG                 0
   #define DEFAULT_SPEED         1200

   #define RING_INTERVAL         1500
   #define MAX_CMD_LEN           256
   #define TX_BUF_SIZE           256
   #define ESC_CHAR              '+'
   #define ESC_COUNT             3
   #define GUARD_TIME            1000
   #define MAGIC_NUMBER          0x4321
   #define MAX_SSID_LEN          32
   #define MAX_WIFI_PWD_LEN      64
   #define DEFAULT_LISTEN_PORT   6400
   #define TELNET_PORT           23
   #define HTTP_PORT             80
   #define SPEED_DIAL_SLOTS      10
   #define MAGIC_ANSWER_RINGS    3
   #define MAX_ALIAS_LEN         16
   #define MAX_SPEED_DIAL_LEN    50
   #define MAGIC_SPEED_LEN       7
   #define MAX_MDNSNAME_LEN      80
   #define MAX_BUSYMSG_LEN       80
   #define MAX_PWD_LEN           80
   #define PASSWORD_TIME         60000
   #define PASSWORD_TRIES        3
   #define MAX_AUTOEXEC_LEN      80
   #define MAX_TERMINAL_LEN      80
   #define MAX_LOCATION_LEN      80

   #define NUL  '\x00'
   #define CTLC '\x03'
   #define BS   '\x08'
   #define LF   '\x0A'
   #define CR   '\x0D'
   #define DEL  '\x7F'

   #define NO_TELNET   ((uint8_t)0)
   #define REAL_TELNET ((uint8_t)1)
   #define FAKE_TELNET ((uint8_t)2)

   // Telnet codes
   #define VLSUP     ((uint8_t)0)
   #define VLREQ     ((uint8_t)1)
   #define LOC       ((uint8_t)23)
   #define TTYPE     ((uint8_t)24)
   #define NAWS      ((uint8_t)31)
   #define TSPEED    ((uint8_t)32)
   #define LFLOW     ((uint8_t)33)
   #define LINEMODE  ((uint8_t)34)
   #define XDISPLOC  ((uint8_t)35)
   #define NEW_ENVIRON ((uint8_t)39)
   #define BINARY    ((uint8_t)0)
   #define ECHO      ((uint8_t)1)
   #define SUP_GA    ((uint8_t)3)
   #define SE        ((uint8_t)240)
   #define SB        ((uint8_t)250)
   #define WILL      ((uint8_t)251)
   #define WONT      ((uint8_t)252)
   #define DO        ((uint8_t)253)
   #define DONT      ((uint8_t)254)
   #define IAC       ((uint8_t)255)

   #define NIST_HOST "time.nist.gov"
   #define NIST_PORT 13

   #define ACTIVE LOW           // RS232 control signals are active low

   // As the ESP8266 is being used as a modem (DCE) in this application,
    // I've reversed the naming of RTS/CTS to match what they'd be on
    // a modem. The usual naming is correct if the ESP8266 is wired up as
    // a DTE, but kept confusing me here as it's wired up as a DCE.
   #ifdef ARDUINO_ESP8266_WEMOS_D1R1
      // D1 R1 pins
      #define CTS D10           // (GPIO15) output
      #define RTS D11           // (GPIO13) input
      #define RI  D12           // (GPIO12) output
      #define DSR D4            // (GPIO04) output
      #define DCD D3            // (GPIO05) output
      #define TXEN D5           // (GPIO14) output
   #endif

   #ifdef ARDUINO_ESP8266_WEMOS_D1MINI
      // D1 mini pins
      #define CTS D8            // (GPIO15) output
      #define RTS D7            // (GPIO13) input
      #define RI  D6            // (GPIO12) output
      #define DSR D2            // (GPIO04) output
      #define DCD D1            // (GPIO05) output
      #define TXEN D5           // (GPIO14) output
   #endif

// added for NodeMCU 0.9 support
   #ifdef ARDUINO_ESP8266_NODEMCU_ESP12
      // D1 mini pins
      #define CTS D8            // (GPIO15) output
      #define RTS D7            // (GPIO13) input
      #define RI  D6            // (GPIO12) output
      #define DSR D2            // (GPIO04) output
      #define DCD D1            // (GPIO05) output
      #define TXEN D5           // (GPIO14) output
   #endif

// added for NodeMCU 1.0 support
    #ifdef ARDUINO_ESP8266_NODEMCU_ESP12E
      // D1 mini pins
      #define CTS D8            // (GPIO15) output
      #define RTS D7            // (GPIO13) input
      #define RI  D6            // (GPIO12) output
      #define DSR D2            // (GPIO04) output
      #define DCD D1            // (GPIO05) output
      #define TXEN D5           // (GPIO14) output
   #endif



#endif

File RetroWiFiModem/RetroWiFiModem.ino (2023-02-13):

//   13/02/2023 S.Orton
//   Modified RetroWiFiModem.h file to add support for NodeMCU
//   Version 0.9 and 1.0 devboards
//
//
//   Retro WiFi modem: an ESP8266 based RS232<->WiFi modem
//   with Hayes style AT commands and blinking LEDs.
//
//   Originally based on
//   Original Source Copyright (C) 2016 Jussi Salin <salinjus@gmail.com>
//   Additions (C) 2018 Daniel Jameson, Stardot Contributors
//   Additions (C) 2018 Paul Rickards <rickards@gmail.com>
//
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

#include <ESP8266WiFi.h>
#include <ESP_EEPROM.h>
#include <WiFiUdp.h>
#include <ArduinoOTA.h>
#include <uart_register.h>
#include <string.h>
#include "RetroWiFiModem.h"
#include "globals.h"
#include "support.h"
#include "at_basic.h"
#include "at_extended.h"
#include "at_proprietary.h"

// =============================================================
void setup(void) {
   bool ok = true;

   pinMode(RI, OUTPUT);
   pinMode(DCD, OUTPUT);
   pinMode(DSR, OUTPUT);
   digitalWrite(TXEN, HIGH);     // continue disabling TX until
   pinMode(TXEN, OUTPUT);        // we have set up the Serial port

   digitalWrite(RI, !ACTIVE);    // not ringing
   digitalWrite(DCD, !ACTIVE);   // not connected
   digitalWrite(DSR, !ACTIVE);   // modem is not ready

   EEPROM.begin(sizeof(struct Settings));
   EEPROM.get(0, settings);
   if( settings.magicNumber != MAGIC_NUMBER ) {
      // no valid data in EEPROM/NVRAM, populate with defaults
      factoryDefaults(NULL);
   }
   sessionTelnetType = settings.telnet;

   Serial.begin(settings.serialSpeed, getSerialConfig());
   digitalWrite(TXEN, LOW);      // enable the TX output
   if( settings.rtsCts ) {
      setHardwareFlow();
   }
   if( settings.startupWait ) {
      while( true ) {            // wait for a CR
         yield();
         if( Serial.available() ) {
            if( Serial.read() == CR ) {
               break;
            }
         }
      }
   }

   WiFi.begin();
   if( settings.ssid[0] ) {
      WiFi.waitForConnectResult();
      WiFi.mode(WIFI_STA);
   }
   WiFiClient::setDefaultNoDelay(true);  // disable Nalge algorithm by default

   if( settings.listenPort ) {
      tcpServer.begin(settings.listenPort);
   }

   if( settings.ssid[0] && WiFi.status() == WL_CONNECTED ) {
      setupOTAupdates();
   }

   if( WiFi.status() == WL_CONNECTED || !settings.ssid[0] ) {
      if( WiFi.status() == WL_CONNECTED ) {
         digitalWrite(DSR, ACTIVE);  // modem is finally ready or SSID not configured
      }
      if( settings.autoExecute[0] ) {
         strncpy(atCmd, settings.autoExecute, MAX_CMD_LEN);
         atCmd[MAX_CMD_LEN] = NUL;
         if( settings.echo ) {
            Serial.println(atCmd);
         }
         doAtCmds(atCmd);                  // auto execute command
      } else {
         sendResult(R_OK);
      }
   } else {
      sendResult(R_ERROR);           // SSID configured, but not connected
   }
}

// =============================================================
void loop(void) {

   checkForIncomingCall();

   switch( state ) {

      case CMD_NOT_IN_CALL:
         if( WiFi.status() == WL_CONNECTED ) {
            ArduinoOTA.handle();
         }
         inAtCommandMode();
         break;

      case CMD_IN_CALL:
         inAtCommandMode();
         if( state == CMD_IN_CALL && !tcpClient.connected() ) {
            endCall();                    // hang up if not in a call
         }
         break;

      case PASSWORD:
         inPasswordMode();
         break;

      case ONLINE:
         if( Serial.available() ) {       // data from RS-232 to Wifi
            sendSerialData();
         }

         while( tcpClient.available() && !Serial.available() ) { // data from WiFi to RS-232
            int c = receiveTcpData();
            if( c != -1 ) {
               Serial.write((char)c);
            }
         }

         if( escCount == ESC_COUNT && millis() > guardTime ) {
            state = CMD_IN_CALL;          // +++ detected, back to command mode
            sendResult(R_OK);
            escCount = 0;
         }

         if( !tcpClient.connected() ) {   // no client?
            endCall();                    // then hang up
         }
         break;
   }
}

// =============================================================
void doAtCmds(char *atCmd) {
   size_t len;

   trim(atCmd);               // get rid of leading and trailing spaces
   if( atCmd[0] ) {
      // is it an AT command?
      if( strncasecmp(atCmd, "AT", 2) ) {
         sendResult(R_ERROR); // nope, time to die
      } else {
         // save command for possible future A/
         strncpy(lastCmd, atCmd, MAX_CMD_LEN);
         lastCmd[MAX_CMD_LEN] = NUL;
         atCmd += 2;          // skip over AT prefix
         len = strlen(atCmd);

         if( !atCmd[0] ) {
            // plain old AT
            sendResult(R_OK);
         } else {
            trim(atCmd);
            while( atCmd[0] ) {
               if( !strncasecmp(atCmd, "?", 1)  ) { // help message
                  // help
                  atCmd = showHelp(atCmd + 1);
               } else if( !strncasecmp(atCmd, "$SB", 3) ) {
                  // query/set serial speed
                  atCmd = doSpeedChange(atCmd + 3);
               } else if( !strncasecmp(atCmd, "$SU", 3) ) {
                  // query/set serial data configuration
                  atCmd = doDataConfig(atCmd + 3);
               } else if( !strncasecmp(atCmd, "$SSID", 5) ) {
                  // query/set WiFi SSID
                  atCmd = doSSID(atCmd + 5);
               } else if( !strncasecmp(atCmd, "$PASS", 5) ) {
                  // query/set WiFi password
                  atCmd = doWiFiPassword(atCmd + 5);
               } else if( !strncasecmp(atCmd, "C", 1) ) {
                  // connect/disconnect to WiFi
                  atCmd = wifiConnection(atCmd + 1);
               } else if( !strncasecmp(atCmd, "D", 1) && len > 2 && strchr("TPI", toupper(atCmd[1])) ) {
                  // dial a number
                  atCmd = dialNumber(atCmd + 2);
               } else if( !strncasecmp(atCmd, "DS", 2) && len == 3 ) {
                  // speed dial a number
                  atCmd = speedDialNumber(atCmd + 2);
               } else if( !strncasecmp(atCmd, "H", 1) || !strncasecmp(atCmd, "H0", 2) ) {
                  // hang up call
                  atCmd = hangup(atCmd + 1);
               } else if( !strncasecmp(atCmd, "&Z", 2) && isDigit(atCmd[2]) ) {
                  // speed dial query or set
                  atCmd = doSpeedDialSlot(atCmd + 2);
               } else if( !strncasecmp(atCmd, "O", 1) ) {
                  // go online
                  atCmd = goOnline(atCmd + 1);
               } else if( !strncasecmp(atCmd, "GET", 3) ) {
                  // get a web page (http only, no https)
                  atCmd = httpGet(atCmd + 3);
               } else if( settings.listenPort && !strncasecmp(atCmd, "A", 1) && tcpServer.hasClient() ) {
                  // manually answer incoming connection
                  atCmd = answerCall(atCmd + 1);
               } else if( !strncasecmp(atCmd, "S0", 2) ) {
                  // query/set auto answer
                  atCmd = doAutoAnswerConfig(atCmd + 2);
               } else if( !strncasecmp(atCmd, "$SP", 3) ) {
                  // query set inbound TCP port
                  atCmd = doServerPort(atCmd + 3);
               } else if( !strncasecmp(atCmd, "$BM", 3) ) {
                  // query/set busy message
                  atCmd = doBusyMessage(atCmd + 3);
               } else if( !strncasecmp(atCmd, "&R", 2) ) {
                  // query/set require password
                  atCmd = doServerPassword(atCmd + 2);
               } else if( !strncasecmp(atCmd, "I", 1) ) {
                  // show network information
                  atCmd = showNetworkInfo(atCmd + 1);
               } else if( !strncasecmp(atCmd, "Z", 1) ) {
                  // reset to NVRAM
                  atCmd = resetToNvram(atCmd + 1);
               } else if( !strncasecmp(atCmd, "&V", 2) ) {
                  // display current and stored settings
                  atCmd = displayAllSettings(atCmd + 2);
               } else if( !strncasecmp(atCmd, "&W", 2) ) {
                  // write settings to EEPROM
                  atCmd = updateNvram(atCmd + 2);
               } else if( !strncasecmp(atCmd, "&F", 2) ) {
                  // factory defaults
                  atCmd = factoryDefaults(atCmd);
               } else if( !strncasecmp(atCmd, "E", 1) ) {
                  // query/set command mode echo
                  atCmd = doEcho(atCmd + 1);
               } else if( !strncasecmp(atCmd, "Q", 1) ) {
                  // query/set quiet mode
                  atCmd = doQuiet(atCmd + 1);
               } else if( !strncasecmp(atCmd, "RD", 2)
                       || !strncasecmp(atCmd, "RT", 2) ) {
                  // read time and date
                  atCmd = doDateTime(atCmd + 2);
               } else if( !strncasecmp(atCmd, "V", 1) ) {
                  // query/set verbose mode
                  atCmd = doVerbose(atCmd + 1);
               } else if( !strncasecmp(atCmd, "X", 1) ) {
                  // query/set extended result codes
                  atCmd = doExtended(atCmd + 1);
               } else if( !strncasecmp(atCmd, "$W", 2) ) {
                  // query/set startup wait
                  atCmd = doStartupWait(atCmd + 2);
               } else if( !strncasecmp(atCmd, "NET", 3) ) {
                  // query/set telnet mode
                  atCmd = doTelnetMode(atCmd + 3);
               } else if( !strncasecmp(atCmd, "$AE", 3) ) {
                  // do auto execute commands
                  atCmd = doAutoExecute(atCmd + 3);
               } else if( !strncasecmp(atCmd, "$TTY", 4) ) {
                  // do telnet terminal type
                  atCmd = doTerminalType(atCmd + 4);
               } else if( !strncasecmp(atCmd, "$TTL", 4) ) {
                  // do telnet location
                  atCmd = doLocation(atCmd + 4);
               } else if( !strncasecmp(atCmd, "$TTS", 4) ) {
                  // do telnet location
                  atCmd = doWindowSize(atCmd + 4);
               } else if( !strncasecmp(atCmd, "&K", 2) ) {
                  // do RTS/CTS flow control
                  atCmd = doFlowControl(atCmd + 2);
               } else if( !strncasecmp(atCmd, "$MDNS", 5) ) {
                  // handle mDNS name
                  atCmd = doMdnsName(atCmd + 5);
               } else {
                  // unrecognized command
                  sendResult(R_ERROR);
               }
               trim(atCmd);
            }
         }
      }
   }
}

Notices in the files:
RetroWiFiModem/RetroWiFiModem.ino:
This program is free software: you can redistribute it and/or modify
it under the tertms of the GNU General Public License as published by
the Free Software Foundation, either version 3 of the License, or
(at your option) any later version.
